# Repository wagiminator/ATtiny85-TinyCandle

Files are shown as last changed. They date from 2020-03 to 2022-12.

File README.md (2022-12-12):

# NeoCandle - Candle Simulation based on ATtiny25/45/85
NeoCandle is a simple tea light candle simulation using 5mm NeoPixels (WS2812), LDR light sensor (GL5528) and IR remote receiver (TSOP4838). It can be controlled by an IR remote control with two buttons and has a timer mode for automatic shutdown after a set time as well as an LDR mode in which the candle is automatically switched on and off depending on the intensity of the ambient light.

- Project Video (YouTube): https://youtu.be/n4UFV3BMcBM
- Design Files (EasyEDA): https://easyeda.com/wagiminator/attiny85-neocandle-dip

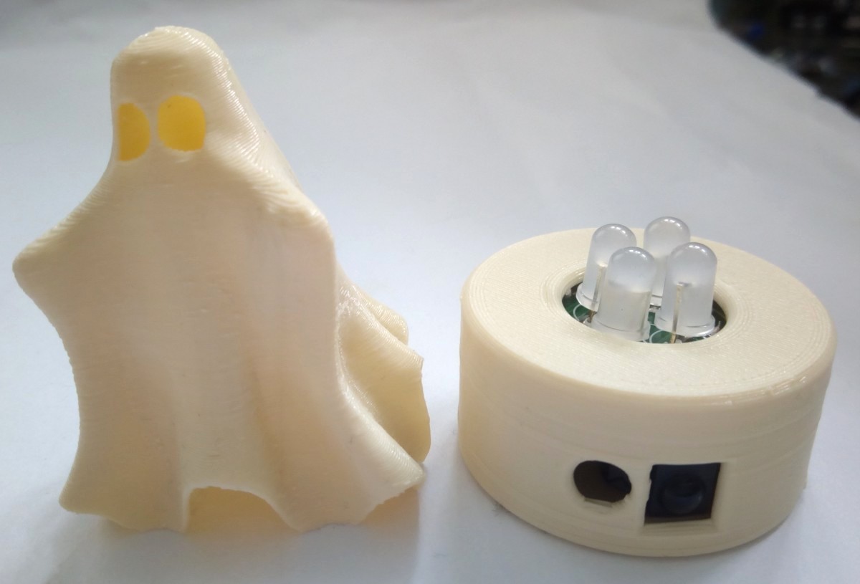
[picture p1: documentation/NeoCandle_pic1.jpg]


# Software
## Candle Simulation
The simulation code is based on the great work of [Mark Sherman](https://github.com/carangil/candle). With most LED candles, the random flickering is rather silly and lacks the spooky element of candlelight: shadows cast by the candle move because the flame is in motion. With NeoCandle, four NeoPixels are arranged in a square, the intensity of the four LEDs forms a "center" of light balance that can be moved around smoothly.

This 'physics-based' candlelight has the following properties:
- The flame has a position and a velocity.
- If the position is not centered, the velocity will accelerate towards the center in proportion to the displacement (hooke's law of springs).
- The velocity has a very small damping value, which means that corrections towards the center always overshoot a bit (underdamped system).
- Random "pushes" into the center position of the light are performed to mimic random drafts.
- The strength of the drafts changes periodically (alternating periods of calm and windiness).

## NeoPixel Implementation
The control of NeoPixels with 8-bit microcontrollers is usually done with software bit-banging. However, this is particularly difficult at low clock rates due to the relatively high data rate of the protocol and the strict timing requirements. The essential protocol parameters for controlling the WS2812 NeoPixels (or similar 800kHz addressable LEDs) can be found in the [datasheet](https://cdn-shop.adafruit.com/datasheets/WS2812.pdf).

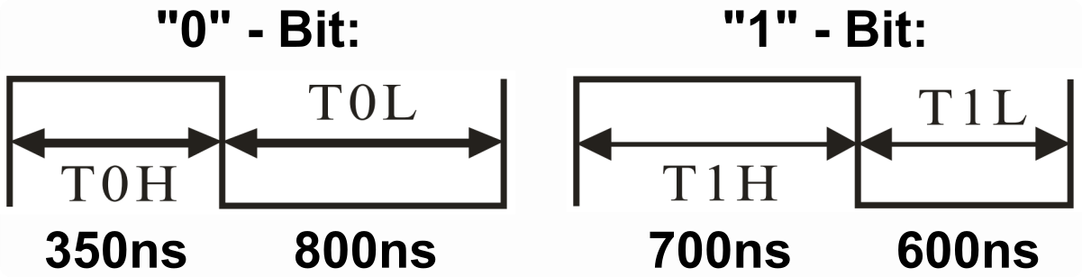
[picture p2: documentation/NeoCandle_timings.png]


Fortunately, the timing is nowhere near as strict as the data sheet suggests. The following timing rules can be derived from the excellent articles by [Josh Levine](https://wp.josh.com/2014/05/13/ws2812-neopixels-are-not-so-finicky-once-you-get-to-know-them/) and [Tim](https://cpldcpu.wordpress.com/2014/01/14/light_ws2812-library-v2-0-part-i-understanding-the-ws2812/) and should **work with all 800kHz addressable LEDs**:

|Pulse|Parameter|Min|Typical|Max|
|:-|:-|-:|-:|-:|
|T0H|"0"-Bit, HIGH time|65 ns|350 ns|500 ns|
|T1H|"1"-Bit, HIGH time|625 ns|700 ns|8500 ns|
|T0L|"0"-Bit, LOW time|450 ns|800 ns|8500 ns|
|T1L|"1"-Bit, LOW time|450 ns|600 ns|8500 ns|
|TCT|Total Cycle Time|1150 ns|1250 ns|9000 ns|
|RES|Latch, LOW time|9 µs|50 µs|280 µs|

Apart from T0H, the maximum values can be even higher, depending on when the NeoPixels actually latch the sent data (with some types only after 280µs!). This also makes it possible to work without a buffer and thus without the use of SRAM. The software essentially only has to ensure that **T0H is a maximum of 500ns and T1H is at least 625ns**, so that the pixels can reliably differentiate "0" from "1" and that the time between sending two bytes is less than the latch time. Assuming that the microcontroller runs with a clock frequency of 8 MHz, the following simple bit-banging function for the transmission of a data byte to the NeoPixels string was implemented:

```c
// Send a byte to the pixels string
void NEO_sendByte(uint8_t byte) {       // CLK  comment
  uint8_t count = 8;                    //      8 bits, MSB first
  asm volatile (
    "sbi  %[port], %[pin]   \n\t"       //  2   DATA HIGH
    "sbrs %[byte], 7        \n\t"       // 1-2  if "1"-bit skip next instruction
    "cbi  %[port], %[pin]   \n\t"       //  2   "0"-bit: DATA LOW after 3 cycles
    "add  %[byte], %[byte]  \n\t"       //  1   byte <<= 1
    "subi %[bit],  0x01     \n\t"       //  1   count--
    "cbi  %[port], %[pin]   \n\t"       //  2   "1"-bit: DATA LOW after 6 cycles
    "brne .-14              \n\t"       //  2   while(count)
    ::
    [port]  "I"   (_SFR_IO_ADDR(PORTB)),
    [pin]   "I"   (NEO_PIN),
    [byte]  "w"   (byte),
    [bit]   "w"   (count)
  );
}
```

When compiled, the function for bit-banging a data byte requires only **18 bytes of flash**. The resulting timing values are shown in the following table:

|Pulse|Parameter|Clock Cycles|Time|
|:-|:-|-:|-:|
|T0H|"0"-Bit, HIGH time|3 Cycles|375 ns|
|T1H|"1"-Bit, HIGH time|6 Cycles|750 ns|
|T0L|"0"-Bit, LOW time|8 Cycles|1000 ns|
|T1L|"1"-Bit, LOW time|4 Cycles|500 ns|
|TCT|Total Cycle Time|11/10 Cycles|1375/1250 ns|

This results in a transfer rate of **762 kbps**, at least for a single data byte. The implementation can certainly still be optimized in terms of speed, but this is already close to the maximum and more than sufficient for controlling only four NeoPixels. Remember that **interrupts should be disabled** during transmission, otherwise the timing requirements cannot be met.

There are three data bytes for each NeoPixel. These are transmitted in the order green, red and blue (this can be different for other types of NeoPixels) with the most significant bit first. The data for the NeoPixel, which is closest to the microcontroller, is output first, then for the next up to the outermost pixel. So this doesn't work like an ordinary shift register! After all color data have been sent, the data line must be kept LOW for at least 9 to 280 µs (depending on the type of NeoPixel) so that the transferred data is latched and the new colors are displayed.

## Pseudo Random Number Generator
The implementation of the candle simulation requires random numbers for a realistic flickering of the candle. However, the usual libraries for generating random numbers require a relatively large amount of memory. Fortunately, Łukasz Podkalicki has developed a [lightweight random number generator](https://blog.podkalicki.com/attiny13-pseudo-random-numbers/) based on [Galois linear feedback shift register](https://en.wikipedia.org/wiki/Linear-feedback_shift_register#Galois_LFSRs) for the ATtiny13A, which is also used here, slightly adapted. When compiled, this function only requires **86 bytes of flash**.

```c
// Start state (any nonzero value will work)
uint16_t rn = 0xACE1;

// Pseudo random number generator
uint16_t prng(uint16_t maxvalue) {
  rn = (rn >> 0x01) ^ (-(rn & 0x01) & 0xB400);
  return(rn % maxvalue);
}
```

## IR Receiver Implementation
The IR receiver implementation is based on [TinyDecoder](https://github.com/wagiminator/ATtiny13-TinyDecoder) and requires **234 bytes of flash**. Only the NEC protocol is supported, but this is used by almost all cheap IR remote controls. Alternatively, you can build such a remote control yourself with [TinyRemote](https://github.com/wagiminator/ATtiny13-TinyRemote).

The IR NEC decoding function utilizes timer1 to measure the burst and pause lengths of the signal. The timer is automatically started and stopped or reset by the IR receiver via a pin change interrupt. The measured lengths are interpreted according to the NEC protocol and the transmitted code is calculated accordingly. The program was tested with the TSOP4838, but it should also work with other 38kHz IR receivers (note different pinout if necessary).

The output of the IR reciever is inverted (active LOW), a burst is indicated by a LOW signal, a pause by a HIGH signal. IR message starts with a 9ms leading burst followed by a 4.5ms pause. Afterwards 4 data bytes are transmitted, least significant bit first. A "0" bit is a 562.5µs burst followed by a 562.5µs pause, a "1" bit is a 562.5µs burst followed by a 1687.5µs pause. A final 562.5µs burst signifies the end of the transmission. According to the data sheet of the TSOP4838, the length of the output signal differs from the transmitted signal by up to 158µs, which the code must take into account. The four data bytes are in order:
- the 8-bit address for the receiving device,
- the 8-bit logical inverse of the address,
- the 8-bit key-dependend command and
- the 8-bit logical inverse of the command.

The Extended NEC protocol uses 16-bit addresses. Instead of sending an 8-bit address and its logically inverse, first the low byte and then the high byte of the address is transmitted. For a more detailed explanation on the NEC protocol refer to [TinyRemote](https://github.com/wagiminator/ATtiny13-TinyRemote). Don't forget to define the used IR codes in the sketch!

```c
// IR codes
#define IR_ADDR       0xEF00  // IR device address
#define IR_PWRON      0x03    // IR code for power on
#define IR_PWROFF     0x02    // IR code for power off
```

## Compiling and Uploading the Firmware
Open the NeoCandle Sketch and adjust the IR codes so that they match your remote control. Remember that only the NEC protocol is supported. If necessary, adjust the values for the LDR light sensor and the switch-off timer.

### If using the Arduino IDE
- Make sure you have installed [ATtinyCore](https://github.com/SpenceKonde/ATTinyCore).
- Go to **Tools -> Board -> ATtinyCore** and select **ATtiny25/45/85 (No bootloader)**.
- Go to **Tools** and choose the following board options:
  - **Chip:**           ATtiny25 or 45 or 85 (depending on your chip)
  - **Clock:**          8 MHz (internal)
  - **Millis/Micros:**  disabled
  - **B.O.D.Level:**    disabled
  - Leave the rest at the default settings
- Connect your programmer to your PC and to the ICSP header on the board.
- Go to **Tools -> Programmer** and select your ISP programmer (e.g. [USBasp](https://aliexpress.com/wholesale?SearchText=usbasp)).
- Go to **Tools -> Burn Bootloader** to burn the fuses.
- Open NeoCandle sketch and click **Upload**.

### If using the precompiled hex-file
- Make sure you have installed [avrdude](https://learn.adafruit.com/usbtinyisp/avrdude).
- Connect your programmer to your PC and to the ISCP header on the board.
- Open a terminal.
- Navigate to the folder with the hex-file.
- Execute the following command (if necessary replace "t85" with your chip and "usbasp" with the programmer you use):
  ```
  avrdude -c usbasp -p t85 -U lfuse:w:0xe2:m -U hfuse:w:0xd7:m -U efuse:w:0xff:m -U flash:w:neocandle.hex
  ```

### If using the makefile (Linux/Mac)
- Make sure you have installed [avr-gcc toolchain and avrdude](http://maxembedded.com/2015/06/setting-up-avr-gcc-toolchain-on-linux-and-mac-os-x/).
- Connect your programmer to your PC and to the ICSP header on the board.
- Open a terminal.
- Navigate to the folder with the makefile and the Arduino sketch.
- Run `DEVICE=attiny85 PROGRMR=usbasp make install` to compile, burn the fuses and upload the firmware (change DEVICE and PROGRMR accordingly).

# Operating Instructions
- Connect a 5V power supply to the Micro-USB socket or a battery to the respective board header.
- The NeoCandle should immediately mimic the flickering of a candle. The device is now in **TIMER mode** and switches off automatically after the time programmed in the code has elapsed. You can switch it off at any time by pressing the power-off button on the IR remote control and switch it back on with the power-on button.
- If the power-on button on the IR remote control is pressed while the NeoCandle is switched on, it changes to **LDR mode**. This change is indicated by a short blue light animation. In LDR mode, NeoCandle switches on and off automatically depending on the intensity of the ambient light. Pressing the power-on or power-off button on the IR remote control switches back to TIMER mode.

# References, Links and Notes
1. [ATtiny25/45/85 Datasheet](https://ww1.microchip.com/downloads/en/DeviceDoc/Atmel-2586-AVR-8-bit-Microcontroller-ATtiny25-ATtiny45-ATtiny85_Datasheet.pdf)
2. [WS2812 Datasheet](https://cdn-shop.adafruit.com/datasheets/WS2812.pdf)
3. [TSOP4838 Datasheet](https://www.vishay.com/docs/82459/tsop48.pdf)
4. [GL5528 Datasheet](https://cdn.sparkfun.com/datasheets/Sensors/LightImaging/SEN-09088.pdf)
5. [Josh Levine's Article about NeoPixels](https://wp.josh.com/2014/05/13/ws2812-neopixels-are-not-so-finicky-once-you-get-to-know-them/)
6. [Tim's Article about NeoPixels](https://cpldcpu.wordpress.com/2014/01/14/light_ws2812-library-v2-0-part-i-understanding-the-ws2812/)
7. [AdaFruit NeoPixel Überguide](https://cdn-learn.adafruit.com/downloads/pdf/adafruit-neopixel-uberguide.pdf)
8. [Candle Simulation Implementation by Mark Sherman](https://github.com/carangil/candle)
9. [Lightweight Random Number Generator by Łukasz Podkalicki](https://blog.podkalicki.com/attiny13-pseudo-random-numbers/)
10. [IR Receiver Implementation](https://github.com/wagiminator/ATtiny13-TinyDecoder)
11. [TinyCandle for ATtiny13A](https://github.com/wagiminator/ATtiny13-TinyCandle)

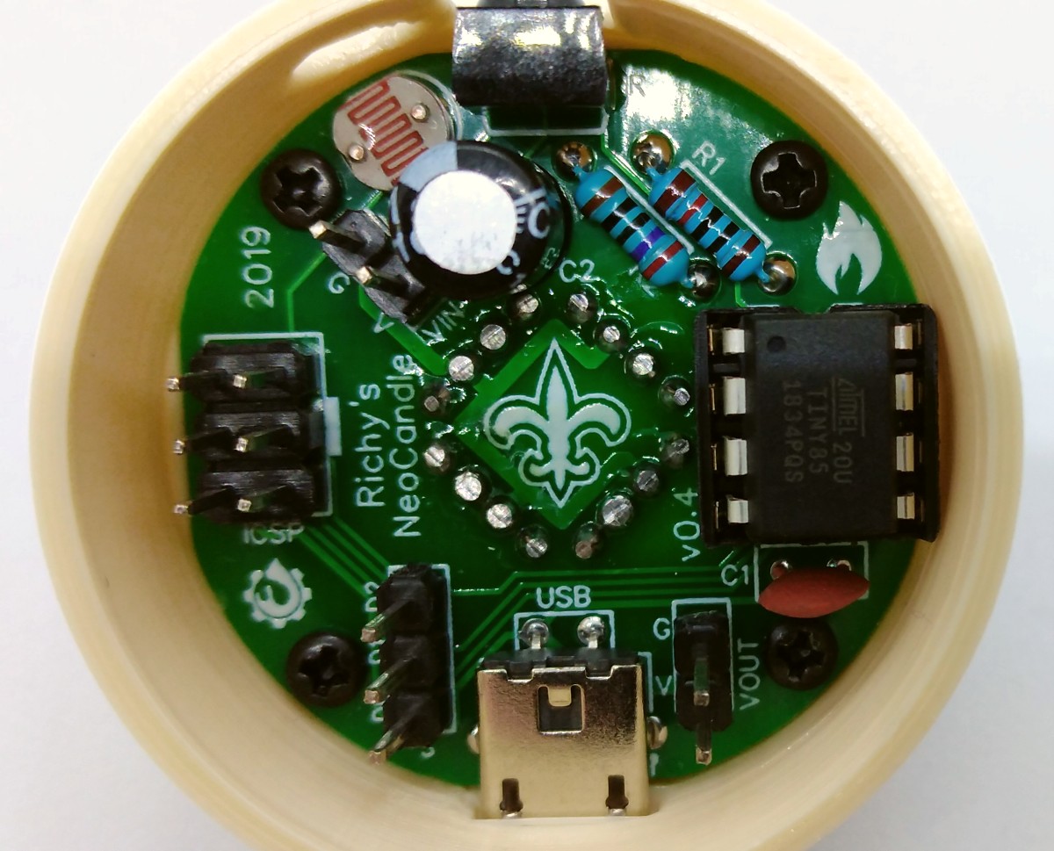
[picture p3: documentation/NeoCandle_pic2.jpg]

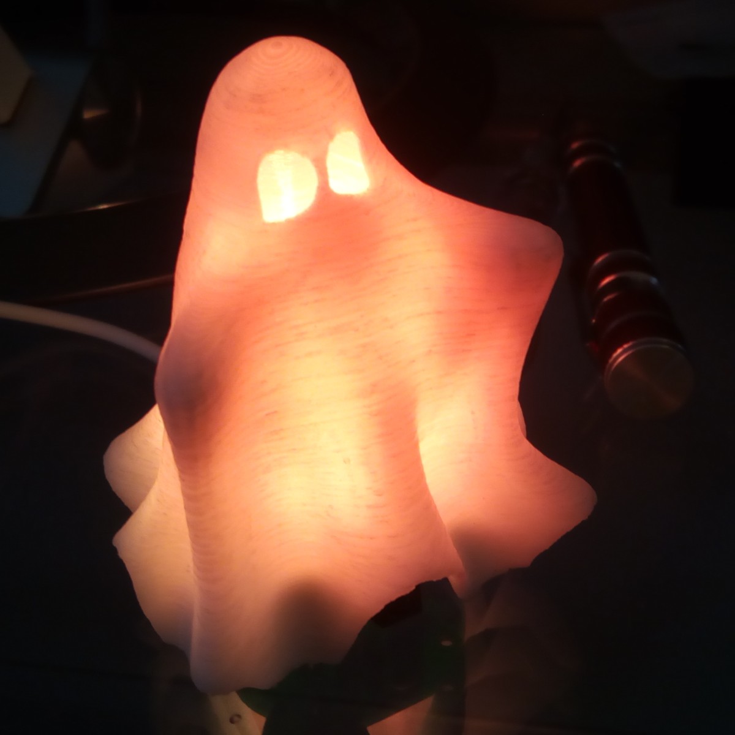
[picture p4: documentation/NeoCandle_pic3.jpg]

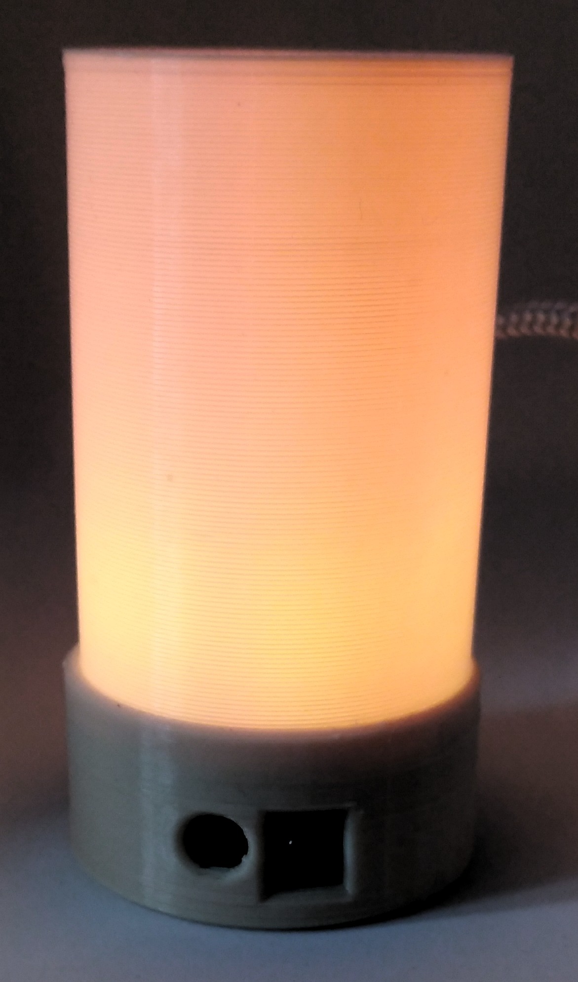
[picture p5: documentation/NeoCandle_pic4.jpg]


# License


This work is licensed under Creative Commons Attribution-ShareAlike 3.0 Unported License. 
(http://creativecommons.org/licenses/by-sa/3.0/)

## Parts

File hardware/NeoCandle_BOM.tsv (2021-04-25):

ID | Name | Designator | Footprint | Quantity | Manufacturer Part | Manufacturer | Supplier | Supplier Part | Price
1 | ATTINY85 | ATTINY | DIP-8 | 1 | ATTINY85-20PU | Microchip
2 | 100n | C1 | RAD-0.1 | 1 | CC1H104ZA1PD3F5P3003 | Dersonic | LCSC | C353903 | 0.0099
3 | 47u | C2 | CP_5X11MM | 1 | 47uF 16V 5*5Black high frequency | ValuePro | LCSC | C47876 | 0.011
4 | ISP | ICSP | HDR-3X2/2.54 | 1 | DS1023-2*3SF11 | CONNFLY | LCSC | C92272 | 0.0477
5 | GL5528 | LDR | RES-PHOTO_CDS | 1 | GL5528 | Senba | LCSC | C125627 | 0.0274
6 | WS2812 NEOPIXEL 5mm LED | LED1,LED2,LED3,LED4 | RGB-5MM | 4 | WS2812D-F5 | Worldsemi | LCSC | C190565 | 0.1258
7 | 10k | R1 | AXIAL-0.3 | 1 | MFR0W4F1002A50 | UniOhm | LCSC | C57436 | 0.0061
8 | 330 | R2 | AXIAL-0.3 | 1 | MFR0W4F3300A50 | UniOhm | LCSC | C58608 | 0.006
9 | 8k2 | R3 | AXIAL-0.3 | 1 | MFR0W4F8201A50 | UniOhm | LCSC | C58598 | 0.0061
10 | PinHeader | S | HDR-3X1/2.54 | 1 | Header2.54mm 1*3P | BOOMELE | LCSC | C49257 | 0.0103
11 | TSOP4838 | U1 | TSOP18XX | 1 | TSOP4838 | VISHAY | LCSC | C124647 | 0.575
12 | MICRO USB 5S B | USB1 | MICRO-USB-1 | 1 | micro USBFemale | ValuePro | LCSC | C10418 | 0.0542
13 | VIN | VIN | HDR-1X2/2.54 | 1 | 2.54-1*2PFemale | BOOMELE | LCSC | C49661 | 0.0285
14 | VOUT | VOUT | HDR-1X2/2.54 | 1 | 2.54-1*2PFemale | BOOMELE | LCSC | C49661 | 0.0285

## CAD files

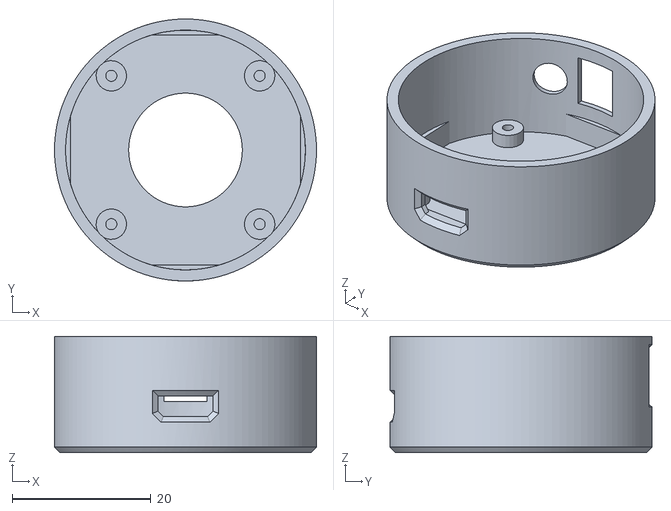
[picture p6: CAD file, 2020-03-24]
3dprint/NeoCandle_case.stl
37.8 x 37.8 x 16.8

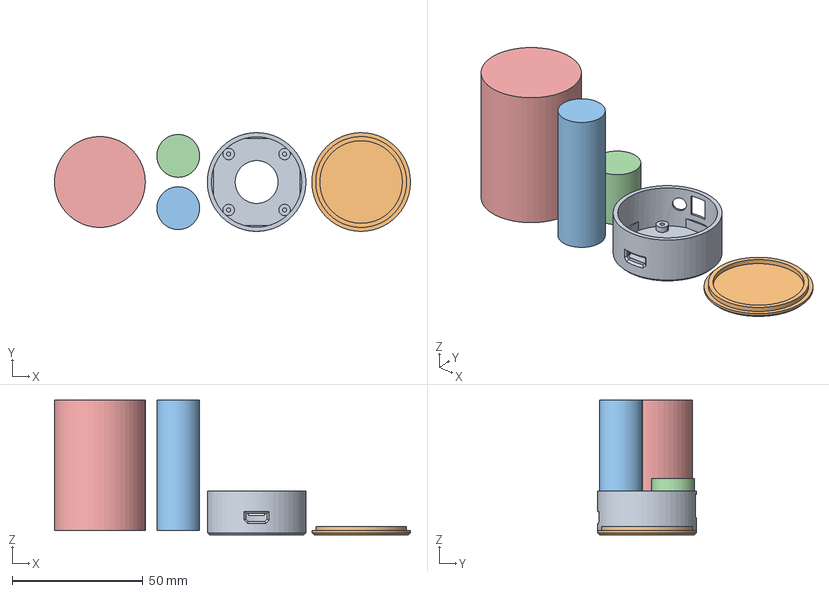
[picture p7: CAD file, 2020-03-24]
3dprint/NeoCandle.fcstd
136.3 x 37.8 x 51.6 mm
Fassung
Deckel
Diffusor groß
Diffusor klein
Schirm

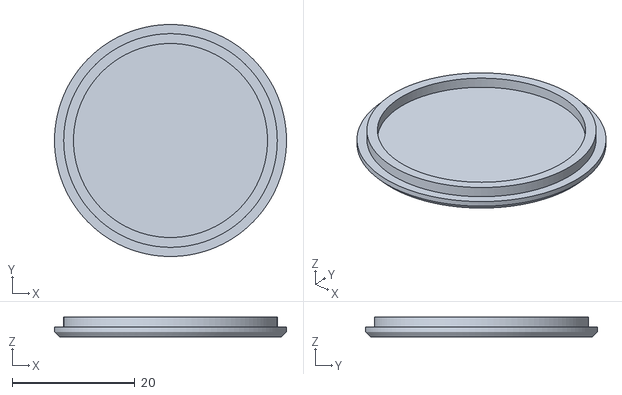
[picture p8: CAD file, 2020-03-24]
3dprint/NeoCandle_cover.stl
37.8 x 37.8 x 3.20

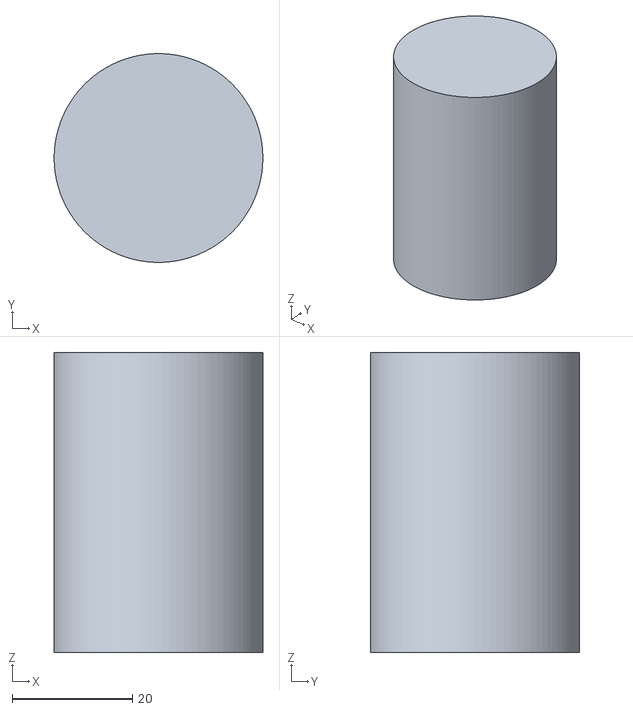
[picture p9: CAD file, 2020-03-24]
3dprint/NeoCandle_shade.stl
34.8 x 34.8 x 50.0

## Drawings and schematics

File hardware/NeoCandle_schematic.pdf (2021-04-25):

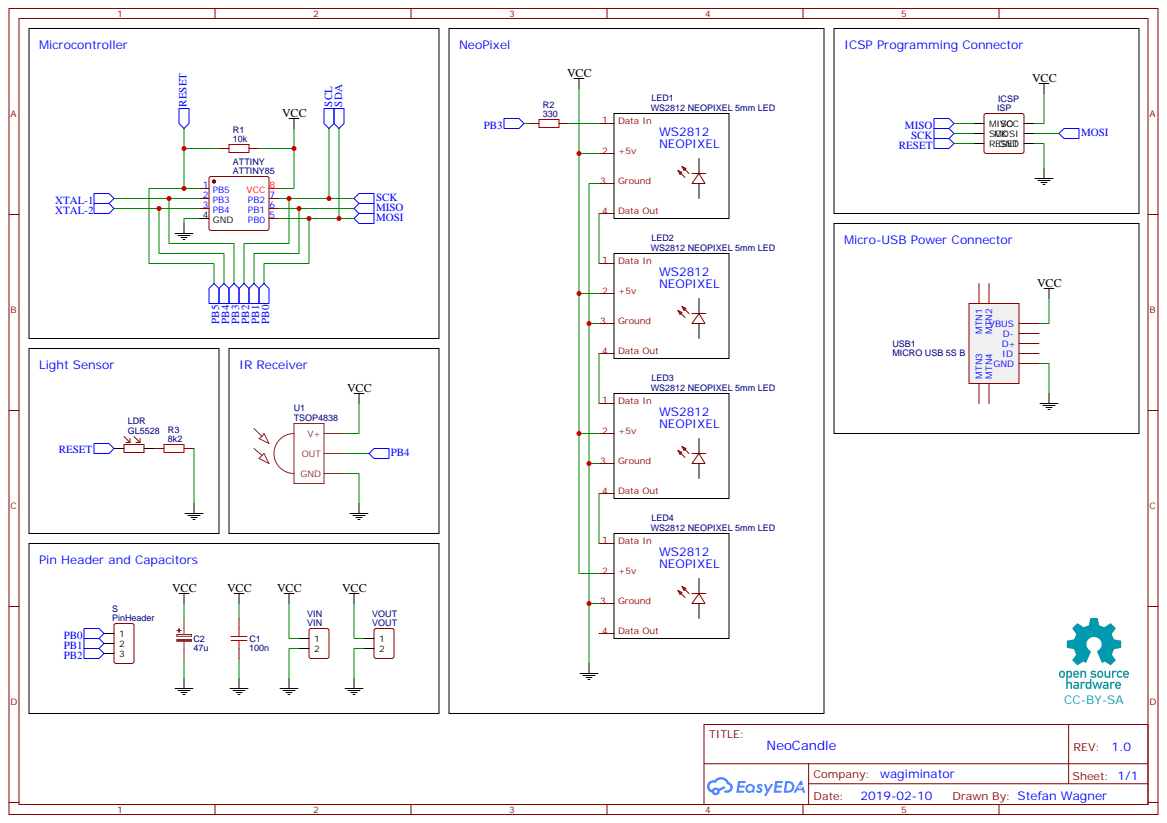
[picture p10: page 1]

Micro-USB Power Connector

Pin Header and Capacitors

Drawn By: Stefan Wagner

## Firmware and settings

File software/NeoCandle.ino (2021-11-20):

// ===================================================================================
// Project:   NeoCandle - Candle Simulation based on ATtiny25/45/85
// Version:   v1.6
// Year:      2019 - 2021
// Author:    Stefan Wagner
// Github:    https://github.com/wagiminator
// EasyEDA:   https://easyeda.com/wagiminator
// License:   http://creativecommons.org/licenses/by-sa/3.0/
// ===================================================================================
//
// Description:
// ------------
// Candle simulation using an ATtiny25/45/85 and four NeoPixels. The candle can
// be controlled by an IR remote control. It can be set into an automatic mode
// in which it's been turned on or off by the intensity of the ambient light.
// The code uses sleep mode in order to decrease power consumption.
//
// References:
// -----------
// The Neopixel implementation was inspired by Josh Levine.
// https://wp.josh.com/category/neopixel/
//
// The simulation code is based on the great work of Mark Sherman.
// https://github.com/carangil/candle
//
// The lightweight pseudo random number generator based on Galois linear feedback
// shift register is taken from Łukasz Podkalicki.
// https://blog.podkalicki.com/attiny13-pseudo-random-numbers/
//
// The IR receiver implementation (NEC protocol) is based on TinyDecoder
// https://github.com/wagiminator/ATtiny13-TinyDecoder
//
// Wiring:
// -------
//                                +-\/-+
//         LDR --- RST ADC0 PB5  1|°   |8  Vcc
//   NEOPIXELS ------- ADC3 PB3  2|    |7  PB2 ADC1 -------- 
// IR RECEIVER ------- ADC2 PB4  3|    |6  PB1 AIN1 OC0B --- 
//                          GND  4|    |5  PB0 AIN0 OC0A --- 
//                                +----+
//
// Compilation Settings:
// ---------------------
// Core:    ATtinyCore (https://github.com/SpenceKonde/ATTinyCore)
// Board:   ATtiny25/45/85 (No bootloader)
// Chip:    ATtiny25 or 45 or 85 (depending on your chip)
// Clock:   8 MHz (internal)
// B.O.D.:  disabled
//
// Leave the rest on default settings. Don't forget to "Burn bootloader"!
// No Arduino core functions or libraries are used. Use the makefile if 
// you want to compile without Arduino IDE.
//
// Note: RESET pin is used as a weak analog input for the LDR light sensor.
//       You don't need to disable the RESET pin as the voltage won't go
//       below 40% of Vcc.
//
// Fuse settings: -U lfuse:w:0xe2:m -U hfuse:w:0xd7:m -U efuse:w:0xff:m 
//
// Operating Instructions:
// -----------------------
// Connect a 5V power supply to the Micro-USB socket or a battery to the respective
// board header. The NeoCandle should immediately mimic the flickering of a candle.
// The device is now in TIMER mode and switches off automatically after the time
// programmed in the code has elapsed. You can switch it off at any time by pressing
// the power-off button on the IR remote control and switch it back on with the
// power-on button. If the power-on button on the IR remote control is pressed while
// the NeoCandle is switched on, it changes to LDR mode. This change is indicated by
// a short blue light animation. In LDR mode, NeoCandle switches on and off
// automatically depending on the intensity of the ambient light. Pressing the
// power-on or power-off button on the IR remote control switches back to TIMER mode.


// ===================================================================================
// Libraries, Definitions and Macros
// ===================================================================================

// Libraries
#include <avr/io.h>                           // for GPIO
#include <avr/wdt.h>                          // for watchdog timer
#include <avr/sleep.h>                        // for sleep modes
#include <avr/interrupt.h>                    // for interrupts
#include <util/delay.h>                       // for delays

// Pins
#define NEO_PIN       PB3                     // Pin for neopixels
#define IR_PIN        PB4                     // Pin for IR receiver
#define LDR_AP        0                       // ADC port of LDR

// IR codes
#define IR_ADDR       0xEF00                  // IR device address
#define IR_PWRON      0x03                    // IR code for power on
#define IR_PWROFF     0x02                    // IR code for power off
#define IR_FAIL       0xFF                    // IR fail code

// LDR parameters
#define LDR_DARK      900                     // LDR ADC threshold value for dark
#define LDR_BRIGHT    800                     // LDR ADC threshold value for bright

// Auto switch off timer
#define AUTOTIMER     (6*3600000)             // after 6 hours

// Global variables
uint32_t timermillis  = 0;                    // timer variable for auto switch off
uint8_t  ldrmode      = 0;                    // LDR mode flag: "1" = LDR mode on

// ===================================================================================
// Neopixel Implementation for 8MHz MCU Clock and 800kHz Pixels
// ===================================================================================

// Neopixel definitions and macros
#define NEO_PIXELS    4                       // number of pixels in the string
#define NEO_init()    DDRB |= (1<<NEO_PIN)    // set pixel DATA pin as output
#define NEO_latch()   _delay_us(251)          // delay to show shifted colors

// Send a byte to the pixels string
void NEO_sendByte(uint8_t byte) {
  uint8_t count = 8;                          // 8 bits, MSB first
  asm volatile (
    "sbi  %[port], %[pin]   \n\t"             // DATA HIGH
    "sbrs %[byte], 7        \n\t"             // if "1"-bit skip next instruction
    "cbi  %[port], %[pin]   \n\t"             // "0"-bit: DATA LOW after 3 cycles
    "add  %[byte], %[byte]  \n\t"             // byte <<= 1
    "subi %[bit],  0x01     \n\t"             // count--
    "cbi  %[port], %[pin]   \n\t"             // "1"-bit: DATA LOW after 6 cycles
    "brne .-14              \n\t"             // while(count)
    ::
    [port]  "I"   (_SFR_IO_ADDR(PORTB)),
    [pin]   "I"   (NEO_PIN),
    [byte]  "w"   (byte),
    [bit]   "w"   (count)
  );
}

// Switch off all pixels
void NEO_clear(void) {
  cli();
  for(uint8_t i = 3 * NEO_PIXELS; i; i--) NEO_sendByte(0);
  sei();
}

// ===================================================================================
// Millis Counter Implementation for Timer0
// ===================================================================================

// Millis counter variable
volatile uint32_t MIL_counter = 0;            // millis counter variable

// Init millis counter
void MIL_init(void) {
  OCR0A  = (F_CPU / 64000UL) - 1;             // TOP-value for 1kHz
  TCCR0A = (1<<WGM01);                        // timer0 CTC mode
  TCCR0B = (1<<CS01) | (1<<CS00);             // start timer0 with prescaler 64
  TIMSK |= (1<<OCIE0A);                       // enable output compare match interrupt
}

// Read millis counter
uint32_t MIL_read(void) {
  cli();                                      // disable interrupt for atomic read
  uint32_t result = MIL_counter;              // read millis counter
  sei();                                      // enable interrupts
  return(result);                             // return millis counter value
}

// Timer0 compare match A interrupt service routine (every millisecond)
ISR(TIM0_COMPA_vect) {
  MIL_counter++;                              // increase millis counter
}

// ===================================================================================
// IR Receiver Implementation (NEC Protocol) using Timer1
// ===================================================================================

// IR receiver definitions and macros
#define IR_available()  (~PINB & (1<<IR_PIN)) // return true if IR line is LOW
#define IR_PRESCALER    512                   // prescaler of the timer
#define IR_time(t)      ((F_CPU / 1000) * t) / IR_PRESCALER / 1000  // convert us to counts
#define IR_TOP          IR_time(12000UL)      // TOP value of timer (timeout)

// IR global variables
volatile uint8_t IR_dur;                      // for storing duration of last burst/pause
volatile uint8_t IR_flag;                     // gets zero in pin change or time over

// IR initialize the receiver
void IR_init(void) {
  PORTB |= (1<<IR_PIN);                       // pullup on IR pin
  PCMSK |= (1<<IR_PIN);                       // enable interrupt on IR pin
  GIMSK |= (1<<PCIE);                         // enable pin change interrupts
  OCR1A  = IR_TOP;                            // timeout causes OCA interrupt
  TIMSK |= (1<<OCIE1A);                       // enable output compare match interrupt
}

// IR wait for signal change
void IR_wait(void) {
  IR_flag = 1;                                // reset flag
  while(IR_flag);                             // wait for pin change or timeout
}

// IR read data according to NEC protocol
uint8_t IR_read(void) {
  uint32_t data;                              // variable for received data
  uint16_t addr;                              // variable for received address
  if(!IR_available()) return IR_FAIL;         // exit if no signal
  IR_wait();                                  // wait for end of start burst
  if(IR_dur < IR_time(8000)) return IR_FAIL;  // exit if no start condition
  IR_wait();                                  // wait for end of start pause
  if(IR_dur < IR_time(4000)) return IR_FAIL;  // exit if no start condition
  for(uint8_t i=32; i; i--) {                 // receive 32 bits
    data >>= 1;                               // LSB first
    IR_wait();                                // wait for end of burst
    if(!IR_dur) return IR_FAIL;               // exit if overflow
    IR_wait();                                // wait for end of pause
    if(!IR_dur) return IR_FAIL;               // exit if overflow
    if(IR_dur > IR_time(1124)) data |= 0x80000000; // bit "0" or "1" depends on pause duration
  }
  IR_wait();                                  // wait for end of final burst
  uint8_t addr1 = data;                       // get first  address byte
  uint8_t addr2 = data >> 8;                  // get second address byte
  uint8_t cmd1  = data >> 16;                 // get first  command byte
  uint8_t cmd2  = data >> 24;                 // get second command byte
  if((cmd1 + cmd2) < 255) return IR_FAIL;     // if second command byte is not the inverse of the first
  if((addr1 + addr2) == 255) addr = addr1;    // check if it's extended NEC-protocol ...
  else addr = data;                           // ... and get the correct address
  if(addr != IR_ADDR) return IR_FAIL;         // wrong address
  return cmd1;                                // return command code
}

// Pin change interrupt service routine
ISR(PCINT0_vect) {
  IR_dur  = TCNT1;                            // save timer value
  TCNT1   = 0;                                // reset timer1
  TCCR1   = (1<<CS13) | (1<<CS11);            // start timer1 with prescaler 512
  IR_flag = 0;                                // raise flag
}

// Timer1 compare match A interrupt service routine (timeout)
ISR(TIM1_COMPA_vect) {
  TCCR1   = 0;                                // stop timer1
  TCNT1   = 0;                                // reset timer1
  IR_flag = 0;                                // raise flag
  IR_dur  = 0;                                // set duration value to zero
}

// ===================================================================================
// ADC and LDR Implementation
// ===================================================================================

// Init ADC for LDR light sensor
void LDR_init(void) {
  ADCSRA = (1<<ADPS2) | (1<<ADPS1);           // set ADC clock prescaler to 64
  ADMUX  = LDR_AP;                            // set LDR port against Vcc
}

// Read LDR sensor value
uint16_t LDR_read(void) {
  PRR &= ~(1<<PRADC);                         // power on ADC
  ADCSRA |= (1<<ADEN) | (1<<ADSC);            // enable ADC and start sampling
  while (ADCSRA & (1<<ADSC));                 // wait for sampling complete
  uint16_t result = ADC;                      // read ADC value;
  ADCSRA &= ~(1<<ADEN);                       // disable ADC
  PRR |= (1<<PRADC);                          // power off ADC
  return result;
}

// Switch on LDR mode
void switchOnLDRmode(void) {
  // Show switching animation
  for(int i=0; i<4; i++) {
    cli();
    for(uint8_t j=0; j<3*NEO_PIXELS; j++)
      (j == ((i << 1) + i + 2)) ? NEO_sendByte(128) : NEO_sendByte(0);
    sei();
    _delay_ms(250);
  }

  // Switch on LDR mode
  ldrmode = 1;
}

// ===================================================================================
// Standby, Sleep and Watchdog Implementation
// ===================================================================================

// Reset watchdog timer
void resetWatchdog(void) {
  cli();                                      // timed sequence coming up
  wdt_reset();                                // reset watchdog
  MCUSR = 0;                                  // clear various reset flags
  WDTCR = (1<<WDCE) | (1<<WDE) | (1<<WDIF);   // allow changes, clear existing interrupt
  WDTCR = (1<<WDIE) | (1<<WDP3)| (1<<WDP0);   // enable watchdog, set interval to 8 seconds
  sei();                                      // interrupts are required now
}

// Go to sleep in order to save energy, wake up again by watchdog timer or pin change interrupt
void sleep(void) {
  GIFR |= (1<<PCIF);                          // clear any outstanding interrupts
  if(ldrmode) resetWatchdog();                // get watchdog ready for LDR mode
  sleep_mode();                               // sleep
}

// Go to standby mode
void gotoStandby(void) {
  NEO_clear();                                // turn off NeoPixels
  
  // Sleep until IR remote power on button is pressed
  while(1) {
    if( (IR_available()) && (IR_read() == IR_PWRON) ) {
      ldrmode = 0;
      timermillis = MIL_read();
      break;
    }
    if(ldrmode && (LDR_read() > LDR_DARK)) break;
    sleep();
  }
}

// Watchdog interrupt service routine
ISR(WDT_vect) {
  wdt_disable();                              // disable watchdog
}

// ===================================================================================
// Pseudo Random Number Generator (adapted from Łukasz Podkalicki)
// ===================================================================================

// Start state (any nonzero value will work)
uint16_t rn = 0xACE1;

// Pseudo random number generator
uint16_t prng(uint16_t maxvalue) {
  rn = (rn >> 0x01) ^ (-(rn & 0x01) & 0xB400);
  return(rn % maxvalue);
}

// ===================================================================================
// Candle Simulation Implementation (adapted from Mark Sherman)
// ===================================================================================

// Candle simulation parameters
#define MINUNCALM     ( 5 * 256)
#define MAXUNCALM     (60 * 256)
#define UNCALMINC     10
#define MAXDEV        100
#define CANDLEDELAY   25

// Some variables
int16_t  centerx   = MAXDEV;
int16_t  centery   = MAXDEV / 2;
int16_t  xvel      = 0;
int16_t  yvel      = 0;
uint16_t uncalm    = MINUNCALM;
int16_t  uncalmdir = UNCALMINC;
uint8_t  cnt       = 0;

// Set one candle LED
void setPixel(int val) {
  if (val > 255) val = 255;   
  if (val < 0  ) val = 0;
  uint8_t byte = (uint8_t)val;
  NEO_sendByte(byte >> 1);
  NEO_sendByte(byte >> 2);
  NEO_sendByte(byte >> 5);
}

// Candle simulation
void updateCandle(void) {
  int movx=0;
  int movy=0;
    
  // Random trigger brightness oscillation, if at least half uncalm
  if(uncalm > (MAXUNCALM / 2)) {
    if(prng(2000) < 5) uncalm = MAXUNCALM * 2;  // occasional 'bonus' wind
  }
   
  // Random poke, intensity determined by uncalm value (0 is perfectly calm)
  movx = prng(uncalm >> 8) - (uncalm >> 9);
  movy = prng(uncalm >> 8) - (uncalm >> 9);
  
  // If reach most calm value, start moving towards uncalm
  if(uncalm < MINUNCALM) uncalmdir =  UNCALMINC;
  
  // If reach most uncalm value, start going towards calm
  if(uncalm > MAXUNCALM) uncalmdir = -UNCALMINC;
  uncalm  += uncalmdir;

  // Move center of flame by the current velocity
  centerx += movx + (xvel >> 2);
  centery += movy + (yvel >> 2); 
  
  // Range limits
  if(centerx < -MAXDEV) centerx = -MAXDEV;
  if(centerx >  MAXDEV) centerx =  MAXDEV;
  if(centery < -MAXDEV) centery = -MAXDEV; 
  if(centery >  MAXDEV) centery =  MAXDEV;

  // Counter
  cnt++;
  if(!(cnt & 3)) {
    // Attenuate velocity 1/4 clicks 
    xvel = (xvel * 999) / 1000;
    yvel = (yvel * 999) / 1000;
  }

  // Apply acceleration towards center, proportional to distance from center (spring motion; hooke's law)
  xvel -= centerx;
  yvel -= centery;

  // Set NeoPixels
  cli();
  setPixel(128 - centerx - centery);
  setPixel(128 + centerx - centery);
  setPixel(128 + centerx + centery);
  setPixel(128 - centerx + centery);
  sei();
}

// ===================================================================================
// Main Function
// ===================================================================================

int main(void) {
  // Reset watchdog timer
  resetWatchdog();                            // do this first in case WDT fires

  // Local variables
  uint32_t lastmillis = 0;

  // Disable unused peripherals and set sleep mode to save power
  ACSR   =  (1<<ACD);                         // disable analog comperator
  DIDR0  = ~(1<<IR_PIN) & 0x1F;               // disable digital intput buffer except IR pin
  PRR    =  (1<<PRUSI) | (1<<PRADC);          // shut down USI and ADC
  set_sleep_mode(SLEEP_MODE_PWR_DOWN);        // set sleep mode to power down

  // Setup
  NEO_init();                                 // init Neopixels
  LDR_init();                                 // init ADC for LDR light sensor
  MIL_init();                                 // init millis counter
  IR_init();                                  // init IR receiver
  sei();                                      // enable global interrupts

  // Loop
  while(1) {
    // Update candle simulation
    if((MIL_read() - lastmillis) > CANDLEDELAY) {
      updateCandle();
      lastmillis = MIL_read();
    }

    // Check for IR remote signals
    if(IR_available()) {
      uint8_t keypressed = IR_read();
      if(keypressed == IR_PWRON) switchOnLDRmode();
      if(keypressed == IR_PWROFF) {
        ldrmode = 0;
        gotoStandby();
      }
    }

    // Turn off candle in daylight when in LDR mode
    if(ldrmode && (LDR_read() < LDR_BRIGHT)) gotoStandby();

    // Check auto switch off timer when not in LDR mode
    if(!ldrmode && ((MIL_read() - timermillis) > AUTOTIMER)) gotoStandby();
  }
}
